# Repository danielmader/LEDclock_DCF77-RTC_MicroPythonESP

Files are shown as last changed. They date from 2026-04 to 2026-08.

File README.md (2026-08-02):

# LEDclock_DCF77-RTC_MicroPythonESP

MicroPython-LED-Uhr auf MAX7219-Punktmatrix-Modulen mit DCF77-Zeitzeichenempfänger,
batteriegepufferter externer RTC (RV-8263), Temperatur-/Luftfeuchtesensor (SHT31)
und Helligkeitssensor (TEMT6000) zur automatischen Display-Dimmung.

Es gibt zwei Hardware-Varianten mit identischer Software:

* **Board 1: ESP-WROOM-32** (NodeMCU)
* **Board 2: ESP32-S3-WROOM-1** (N16R8)

Boardvarianten & Pinbelegung
----------------------------

Die Pinbelegung liegt nicht mehr im Code, sondern in JSON-Dateien in `src/`:

* `board_esp-wroom-32.json` — Board 1
* `board_esp32-s3-wroom-1.json` — Board 2

Das Modul `src/boardconfig.py` erkennt das Board zur Laufzeit automatisch
(über `os.uname().machine`) und lädt die passende Datei. Es genügt also, beide
JSON-Dateien mit auf das Gerät zu kopieren. Für Sonderaufbauten kann eine Datei
`board.json` auf dem Gerät abgelegt werden, die dann Vorrang hat.

| Funktion / Peripherie | Signal | ESP-WROOM-32 | ESP32-S3-WROOM-1 | Anmerkung |
| :--- | :--- | :--- | :--- | :--- |
| I2C (RV-8263, SHT31)  | SDA | GPIO23 | GPIO8 | 50 kHz, interne Pull-ups |
| | SCL | GPIO22 | GPIO9 | |
| TEMT6000 | ADC | GPIO36 (ADC1_CH0) | GPIO4 (ADC1_CH3) | zwingend ADC1 (ADC2 kollidiert mit Wi-Fi) |
| DCF77 | DATA | GPIO13 | GPIO14 | Eingang mit Pull-up |
| MAX7219 | DIN (MOSI)  | GPIO19 | GPIO42 | S3: GPIO19/20 sind USB! |
| | SCLK | GPIO5 | GPIO1 | |
| | CS | GPIO18 | GPIO2 | |
| MAX7219 Power ON/OFF  | GPIO out | – | GPIO21 | optional (`null` in JSON = nicht beschaltet) |
| Status-LED | GPIO out | GPIO2 | – | S3-DevKit hat nur RGB-LED (GPIO48) |

Wichtige Hinweise zum ESP32-S3 (Details in `hardware/Pinout Proposal.md`):

* **GPIO19/20** sind das native USB-Interface — nicht extern beschalten.
* **GPIO0** ist Strapping-Pin (Bootloader) — nicht als Power-Control verwenden.
* **N16R8 (8 MB Octal-PSRAM):** GPIO33–37 sind intern belegt; die herausgeführten
  GPIO35–37 dürfen **nicht** beschaltet werden.

Batterie-Backup für RV-8263 RTC
-------------------------------

Anschlüsse am Beispiel ESP-WROOM-32 (beim ESP32-S3: SDA = GPIO8, SCL = GPIO9):

    ESP-WROOM-32 NodeMCU

    VCC (3.3V ESP) -----------------+-------+-------+
                                    |       |       |
                                    [R1]    [R2]    [D1] (Schottky)
                                    10k     10k     |
                                    |       |       |
    SDA (GPIO 23) ------------------+----------------------- SDA (RV-8263)
                                            |       |
    SCL (GPIO 22) --------------------------+--------------- SCL (RV-8263)
                                                    |
                                                    +------- VCC (RV-8263)
                                                    |
    Batterie (+) ----------[D2] (Schottky) ---------+
    (Knopfzelle)

    GND (ESP) --------------------------------------+------- VSS (RV-8263)
                                                    |
    Batterie (-) -----------------------------------+

* R1 = R2: 10 kOhm
* D1 = D2: Schottky-Diode BAT 42/43 oder BAT 86

Schaltbild Peripherie (ohne Backup-Batterie)
--------------------------------------------

Verdrahtungspläne für beide Boards liegen in `hardware/`:

* [Wiring Diagram ESP-WROOM-32](./hardware/Wiring%20Diagram_ESP-WROOM-32.png) ([PDF](./hardware/Wiring%20Diagram_ESP-WROOM-32.pdf))
* [Wiring Diagram ESP32-S3-WROOM-1](./hardware/Wiring%20Diagram_ESP32-S3-WROOM-1.png) ([PDF](./hardware/Wiring%20Diagram_ESP32-S3-WROOM-1.pdf))

ASCII-Übersicht am Beispiel ESP-WROOM-32:

    ESP-WROOM-32 NodeMCU

    3V3  -----------------------------------+------------------+------------------+
                                            |                  |                  |
                                            |                  |                  +---- VCC (MAX7219)
                                            |                  +----------------------- VCC (TEMT6000)
                                            +------------------------------------------ VCC (I2C: RV-8263, SHT31)

    5V (VIN) --------------------------------------------------- VCC (DCF77)

    GND  -----------------------------------+------------------+------------------+------------------+
                                            |                  |                  |                  |
                                            |                  |                  |                  +---- GND (MAX7219)
                                            |                  |                  +---- GND (DCF77)
                                            |                  +----------------------- GND (TEMT6000)
                                            +------------------------------------------ VSS (I2C: RV-8263, SHT31)

    GPIO23 (SDA) ---------------------------+------------------ SDA (RV-8263)
                                            |
                                            +------------------ SDA (SHT31)

    GPIO22 (SCL) ---------------------------+------------------ SCL (RV-8263)
                                            |
                                            +------------------ SCL (SHT31)

    GPIO36 (ADC) ------------------------------------------------ AO/OUT (TEMT6000)

    GPIO13 -------------------------------------------------------- DATA/OUT (DCF77)

    GPIO19 (SPI MOSI) ------------------------------------------------ DIN (MAX7219)

    GPIO18 (SPI CS) -------------------------------------------------- CS (MAX7219)

    GPIO5  (SPI SCLK) ------------------------------------------------ SCLK (MAX7219)

Hinweis DCF77 Versorgung
------------------------

- Der DCF77-Empfänger kann mit 5V versorgt werden; das ist für die Signalqualität
  oft etwas robuster.
- Wichtig: Das DCF77-Datensignal muss dann auf 3.3V-Pegel zum ESP32 angepasst
  werden (Spannungsteiler, Pegelwandler oder Open-Collector mit 3.3V Pull-up).
- Läuft das Modul sauber mit 3.3V, ist das meist die einfachste und sicherste
  Lösung, weil kein Pegelwandler nötig ist.
- DCF77-Empfänger reagieren empfindlich auf Wi-Fi-Störungen und sollten räumlich
  getrennt vom ESP32 platziert werden.

Software
--------

Die Skripte liegen in `src/`:

* `main.py` — Hauptprogramm (asyncio-Tasks: DCF77-Empfang, Zeit-Sync, Sensorik, Anzeige)
* `boardconfig.py` — lädt die Pinbelegung aus `board_*.json` (Auto-Erkennung)
* `dcf77.py` — DCF77-Dekoder
* `rv8263.py` — Treiber externe RTC RV-8263
* `sht31.py` — Treiber Temperatur-/Feuchtesensor SHT31
* `temt6000.py` — Treiber Helligkeitssensor TEMT6000
* `max7219wrapper.py`, `characters.py` — Display-Ansteuerung und Fonts
* `lib/max7219.py` — MAX7219-Basistreiber (mcauser), auf dem Gerät nach `/lib`
* `playground/` — Diagnose-Skripte (DCF77-Analyzer, I2C-Diagnose)

Deployment z.B. mit `mpremote`: alle `.py` aus `src/` sowie **beide**
`board_*.json` ins Wurzelverzeichnis des Geräts kopieren, `src/lib/max7219.py`
nach `/lib/max7219.py`.

Entwicklung: Linting & Typechecking
-----------------------------------

### Einrichtung der venv

Die Konfigurationen (`pyrightconfig.json`, `scripts/update-typeshed.sh`) erwarten
die venv unter `.venv` mit **Python 3.11**. Einrichtung wahlweise mit pip oder uv:

    ## Variante A: pip/venv
    python3.11 -m venv .venv
    .venv/bin/pip install -r requirements.txt

    ## Variante B: uv
    uv venv --python 3.11 .venv
    uv pip install -r requirements.txt

    ## Danach in beiden Fällen: kombiniertes Typeshed für ty erzeugen
    ./scripts/update-typeshed.sh

`requirements.txt` enthält alles Nötige:

* `micropython-esp32-stubs` — Typ-Stubs für `machine`, `network`, `time.ticks_ms()`
  usw. (zieht `micropython-stdlib-stubs` automatisch mit)
* `basedpyright` — Typechecker, gleiche Engine wie Pylance
* `ty` — Typechecker von Astral (Hersteller von ruff/uv)
* `ruff` — Linter (Import-Sortierung, Code-Stil, Komplexität)

*(Hinweis: Das npm-Paket `pyright` selbst braucht eine Node-Runtime mit
`libatomic.so.1` — `basedpyright` bringt dagegen alles als Python-Wheel mit
und liest dieselbe `pyrightconfig.json`.)*

### Checker ausführen

    .venv/bin/basedpyright src    ## Konfiguration: pyrightconfig.json
    .venv/bin/ty check            ## Konfiguration: pyproject.toml [tool.ty]
    .venv/bin/ruff check src      ## Linter, Konfiguration: pyproject.toml [tool.ruff]

Alle drei müssen fehlerfrei durchlaufen (Stand der letzten Bereinigung:
0 Fehler / "All checks passed").

### Wie die Stub-Auflösung funktioniert (wichtig bei Problemen)

Die MicroPython-Stubs liegen nach der Installation **flach** in den
site-packages (`time.pyi`, `machine.pyi`, ...), zusätzlich liefert
`micropython-stdlib-stubs` ein partielles `stdlib/`-Verzeichnis (u.a. `asyncio`
mit `sleep_ms`). Die beiden Checker finden sie unterschiedlich:

* **basedpyright/Pylance:** über `stubPath` **und** `typeshedPath` in
  `pyrightconfig.json` — beide zeigen auf
  `.venv/lib/python3.11/site-packages`. Bei einem Wechsel der Python-Version
  müssen diese Pfade angepasst werden!
* **ty:** kennt keinen `stubPath`, sondern nur ein komplettes Ersatz-Typeshed
  (`[tool.ty.environment].typeshed = ".typeshed"` in `pyproject.toml`).
  `scripts/update-typeshed.sh` baut dieses Verzeichnis aus den installierten
  Stubs zusammen (stdlib-Stubs + das dort fehlende `time.pyi`).
  **Nach jedem Update der Stubs erneut ausführen:**

      .venv/bin/pip install -U micropython-esp32-stubs   ## bzw. uv pip install -U ...
      ./scripts/update-typeshed.sh

### Bekannte Stolperfallen (ty 0.0.65)

* Das generierte Typeshed darf **nicht** `typings/` heißen (implizites
  Stub-Verzeichnis von ty → Absturz "dependency graph cycle"). Deshalb `.typeshed/`.
* `src` nicht zusätzlich in `[tool.ty.environment].extra-paths` eintragen —
  es ist bereits First-Party-Root, die Doppelung führt ebenfalls zum Absturz.
* ty versteht mypy-Fehlercodes nicht: `# type: ignore[operator]` unterdrückt
  nur Pylance/basedpyright. Für ty muss zusätzlich `# ty: ignore[<regel>]` an
  die Zeile (Beispiele in `main.py` bei der Driftkompensation).
* Ticks sind in den Stubs bewusst opak typisiert (`_TicksMs`): direkte
  Arithmetik wie `ticks_ms() % 1000` wird angemeckert — gewollt ist
  `time.ticks_diff()` / `time.ticks_add()`.

### VSCode

Empfohlene Extensions: **Pylance** (oder basedpyright) und **ty**. Damit die
Extensions die Checker aus der venv verwenden, stehen in der Workspace-Datei
(`*.code-workspace` ist gitignored, ggf. neu anlegen):

    "settings": {
        "python.defaultInterpreterPath": "${workspaceFolder}/.venv/bin/python",
        "ty.importStrategy": "fromEnvironment",
        "basedpyright.importStrategy": "fromEnvironment"
    }

ASCII-Boardplan DIN-Lochraster 32x54 (einseitig, ESP-WROOM-32)
--------------------------------------------------------------

Schienen horizontal, Signale vertikal mit Drahtbruecken.

        +----------------------------------------------------+
    01  |5V==================================================|
        |....................................................|
        |3V3=================================================|
        |....................................................|
    05  |GND=================================================|
        |....................................................|
        |SDA=================================================|
        |SCL=================================================|
        |....................................................|
    10  |...................ESP32 NodeMCU....................|
        |   L01 3V3    o......................o GND    R01   |
        |   L02 RESET  o......................o GPIO23 R02   |
        |   L03 GPIO36 o......................o GPIO22 R03   |
        |   L04 GPIO39 o......................o INT    R04   |
    15  |   L05 GPIO34 o......................o INT    R05   |
        |   L06 GPIO35 o......................o GPIO21 R06   |
        |   L07 GPIO32 o......................o GND    R07   |
        |   L08 GPIO33 o......................o GPIO19 R08   |
        |   L09 GPIO25 o......................o GPIO18 R09   |
    20  |   L10 GPIO26 o......................o GPIO5  R10   |
        |   L11 GPIO27 o......................o GPIO17 R11   |
        |   L12 GPIO14 o......................o GPIO16 R12   |
        |   L13 GPIO12 o......................o GPIO4  R13   |
        |   L14 GND    o......................o GPIO0  R14   |
    25  |   L15 GPIO13 o......................o GPIO2  R15   |
        |   L16 INT    o......................o GPIO15 R16   |
        |   L17 INT    o......................o INT    R17   |
        |   L18 INT    o......................o INT    R18   |
        |   L19 5V     o......................o INT    R19   |
    30  |....................................................|
        |....................................................|
        |....................................................|
        +----------------------------------------------------+

Pinouts
-------

### RV-8263
* NC
* Vss
* NC (CLKOE)
* NC (INT)
* VDD
* NC (CLKOUT)
* SCL
* SDA

### SHT31
* VING
* GND
* SCL
* SDA

### TEMT6000
* OUT
* GND
* VCC

### DCF77
* VIN
* SIG
* GND

### MAX7219
* VCC
* GND
* DIN
* CS
* CLK

Lochrasterplatinenlayout
------------------------

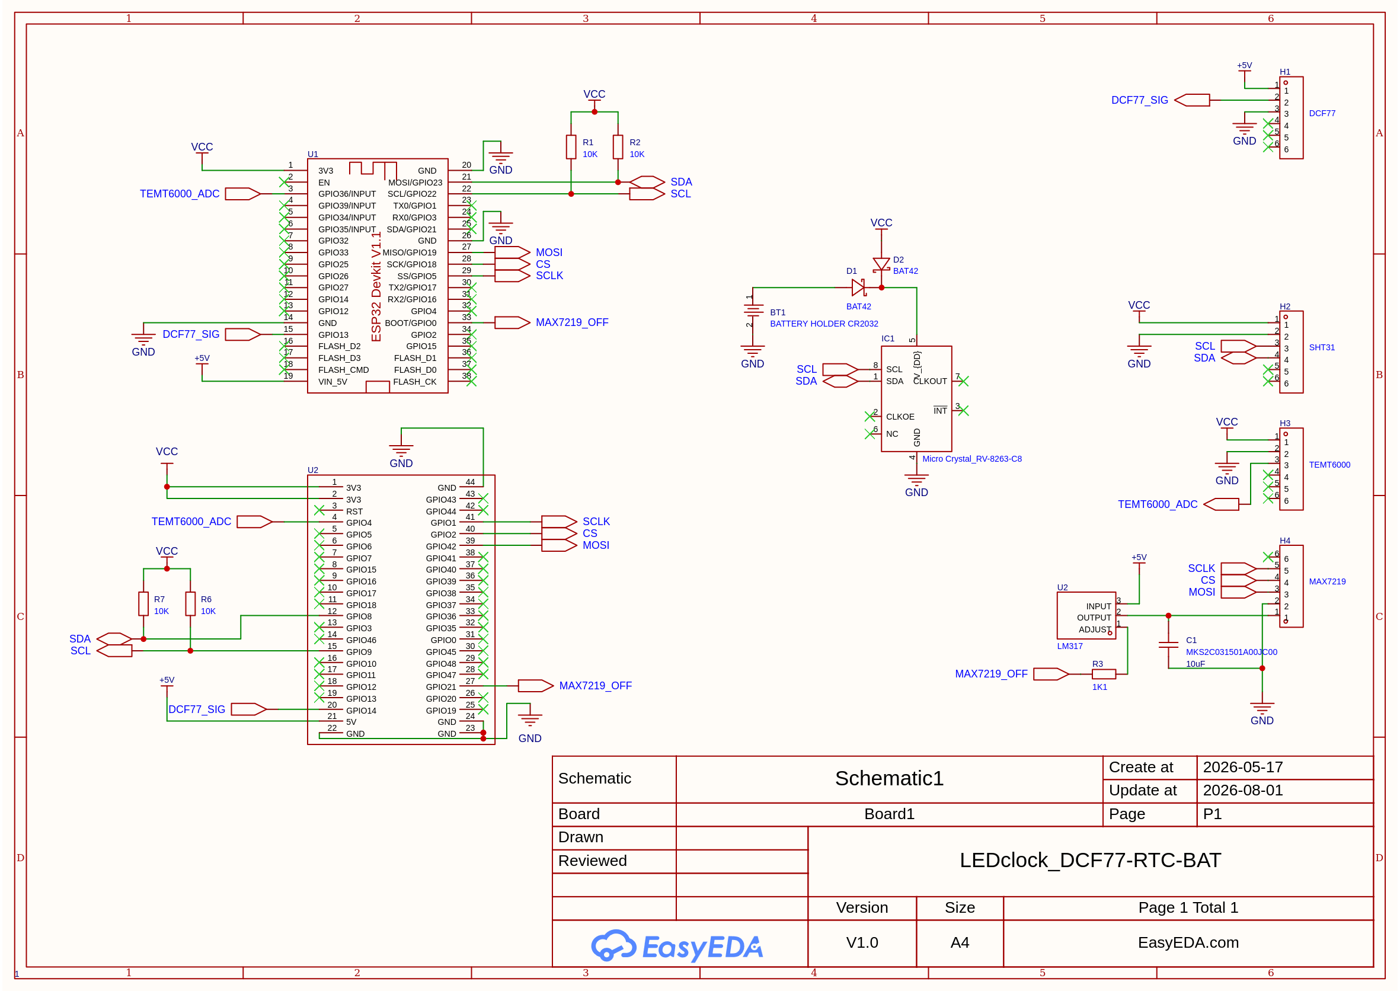
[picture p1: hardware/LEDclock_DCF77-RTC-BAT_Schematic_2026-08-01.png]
Schaltplan


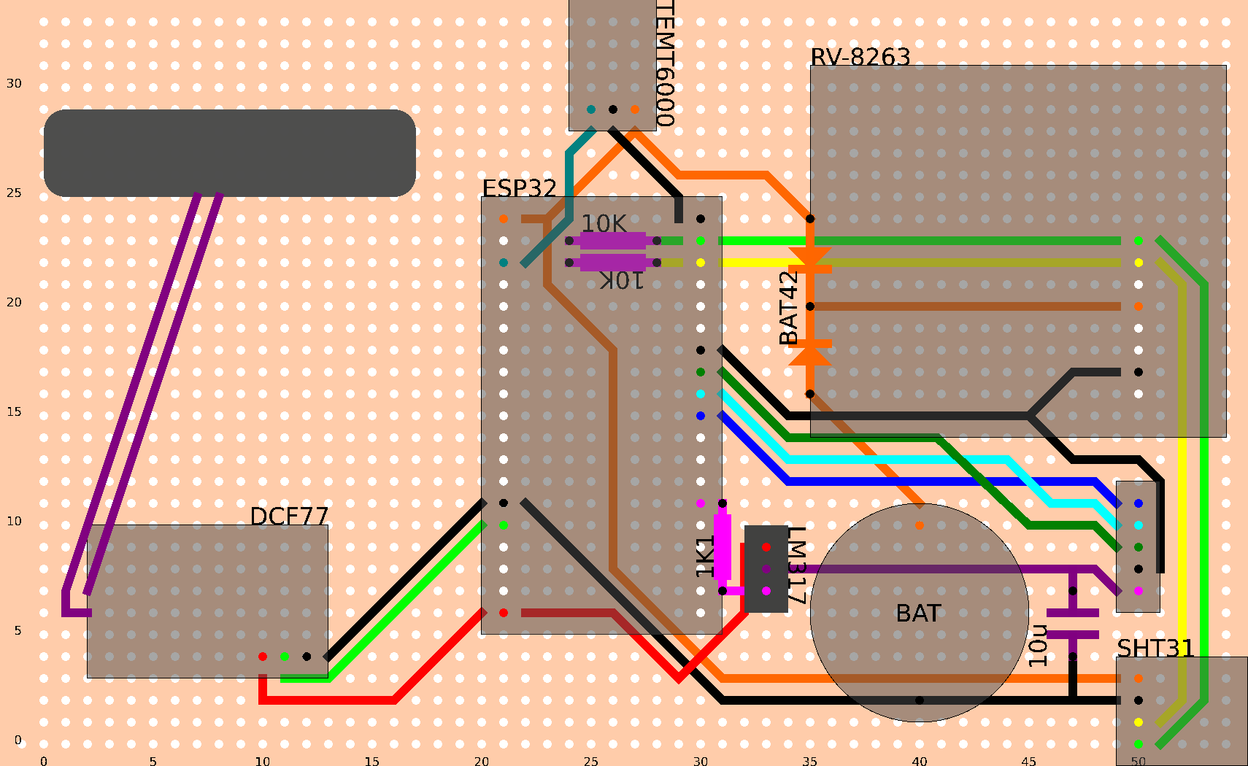
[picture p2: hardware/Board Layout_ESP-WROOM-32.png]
Board Layout ESP-WROOM-32


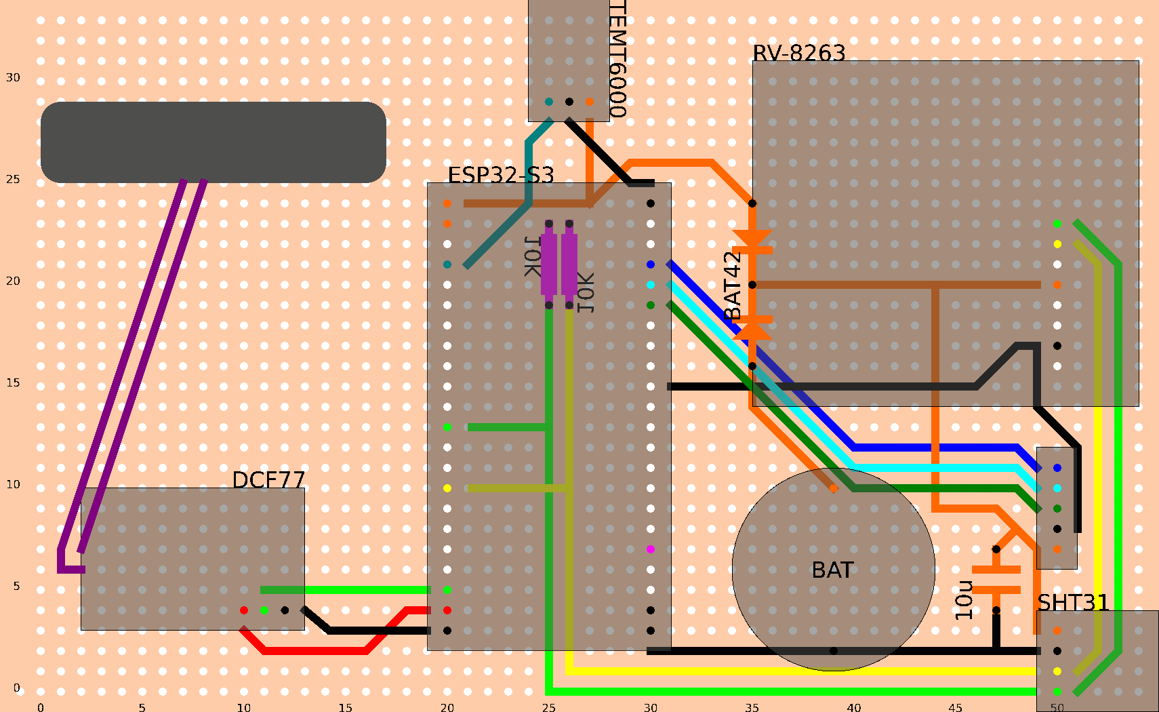
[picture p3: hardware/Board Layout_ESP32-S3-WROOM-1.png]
Board Layout ESP32-S3-WROOM-1


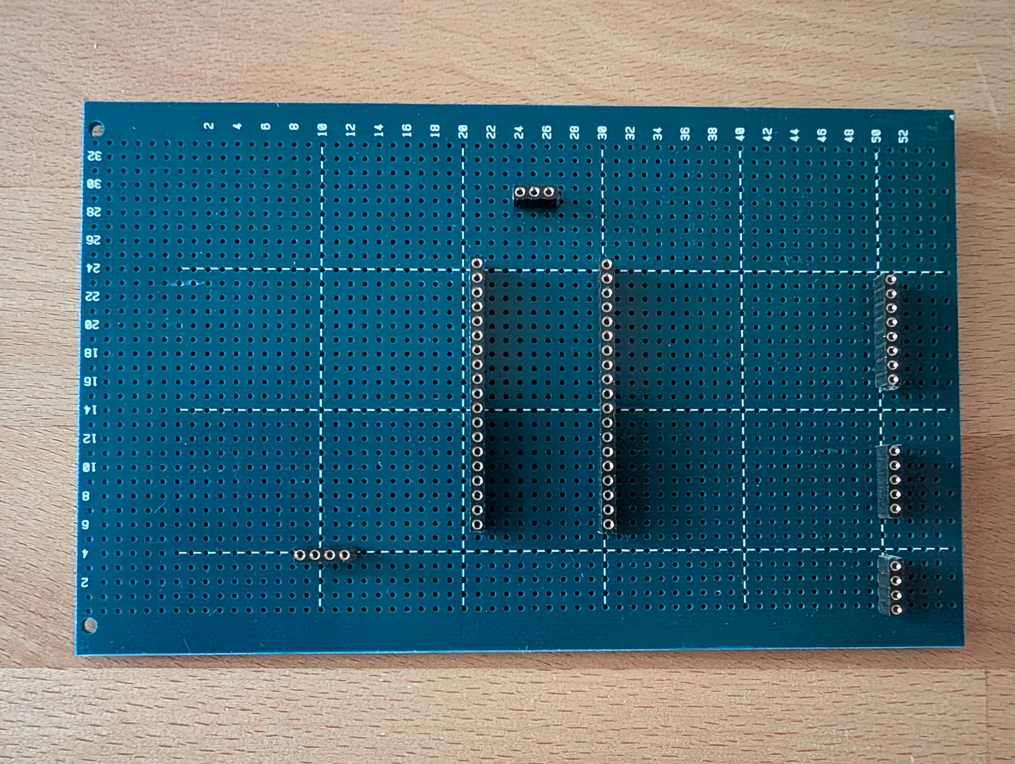
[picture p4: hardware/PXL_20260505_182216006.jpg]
Grundriss


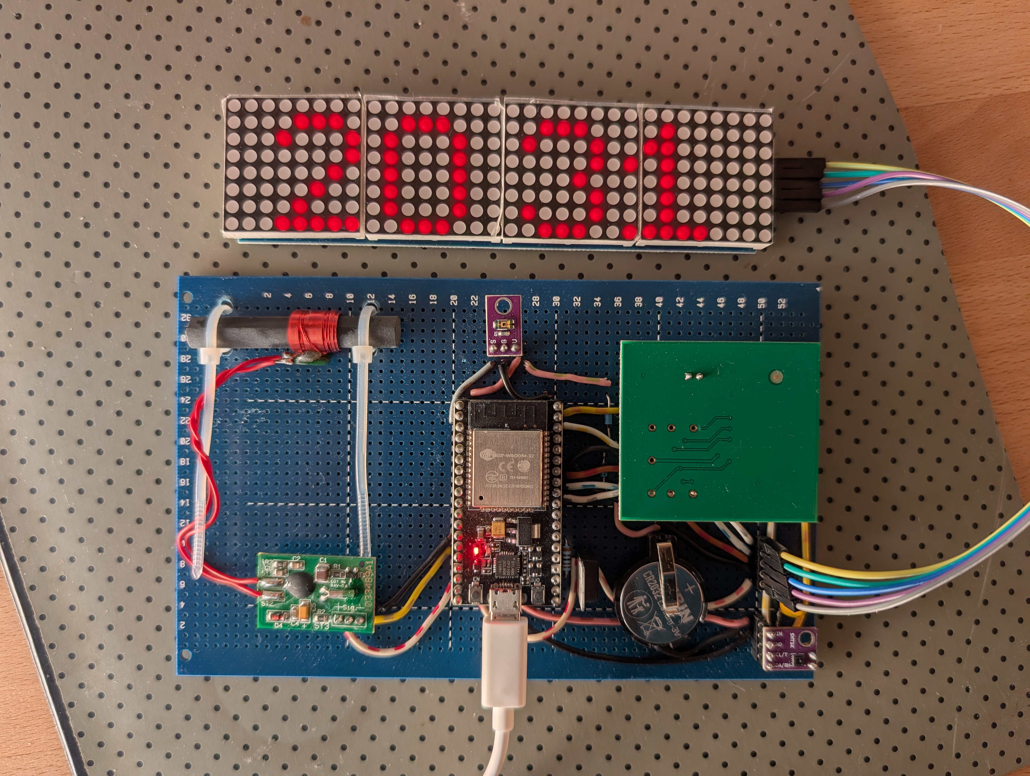
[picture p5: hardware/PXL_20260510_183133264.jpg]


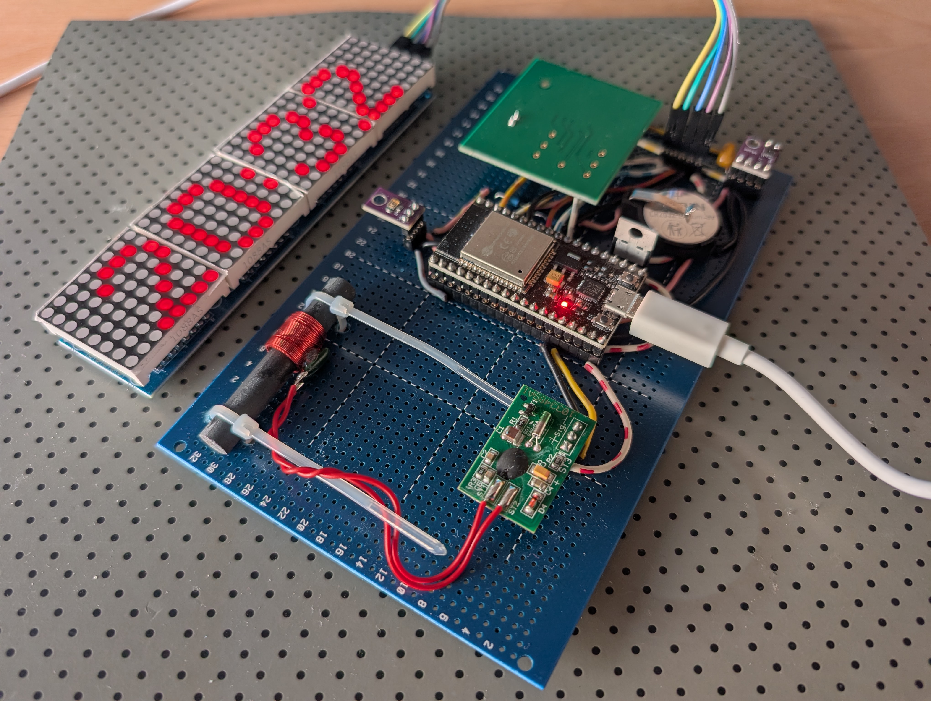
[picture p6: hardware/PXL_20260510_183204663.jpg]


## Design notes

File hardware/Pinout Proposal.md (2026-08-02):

# Pinbelegungs-Dokumentation: ESP-WROOM-32 vs. ESP32-S3-WROOM-1

Beim Upgrade vom klassischen **ESP-WROOM-32** auf den neueren **ESP32-S3-WROOM-1** ändern sich einige Hardware-Peripherien und Standard-Pinbelegungen. Dank der flexiblen **GPIO-Matrix** (GPIO Mux) des ESP32 lassen sich viele Signale im Code frei auf andere Pins umleiten. Dennoch müssen spezifische Board-Eigenschaften (Strapping-Pins, USB-Interfaces, Octal-PSRAM) beachtet werden.

---

## 1. I2C-Bus (Temperatur-Sensor SHT31 & RTC RV-8263)

Beide I2C-Sensoren liegen parallel als Bus-Teilnehmer an denselben zwei Leitungen (`SDA` und `SCL`).

* **ESP-WROOM-32 (Standard):** `GPIO 23` (SDA) und `GPIO 22` (SCL).
* **ESP32-S3 (Standard):** `GPIO 8` (SDA) und `GPIO 9` (SCL).
* **Begründung & Wahl:**
  Beim Wechsel auf den ESP32-S3 wurden die neuen Hardware-Defaults **GPIO 8 (SDA)** und **GPIO 9 (SCL)** übernommen. Diese Pins sind frei von Strapping-Funktionen und ideal für I2C geeignet.

---

## 2. ADC / Analog-Eingang (TEMT6000 Helligkeitssensor)

Der analoge Lichtsensor benötigt einen ADC-Pin.

* **ESP-WROOM-32:** `GPIO 36` (VP / ADC1_CH0).
* **ESP32-S3:** `GPIO 4` (ADC1_CH3).
* **Begründung & Wahl:**
  Auf beiden Boards muss zwingend ein Kanal des **ADC1** gewählt werden, da ADC2 deaktiviert wird, sobald Wi-Fi aktiv genutzt wird. Beim ESP32-S3 fällt die Wahl auf **GPIO 4**, was ein unproblematischer ADC1-Eingang ist.
  *(Hinweis: Pins wie GPIO 35–37 dürfen beim S3-Board keinesfalls genutzt werden – siehe Abschnitt 6).*

---

## 3. GPIO Input (DCF77-Zeitsignal)

Das DCF77-Signal ist sehr langsam und benötigt keinen speziellen Hardware-Schnittstellen-Pin.

* **ESP-WROOM-32:** `GPIO 13`.
* **ESP32-S3:** `GPIO 14`.
* **Begründung & Wahl:**
  Auf beiden Boards wird ein Standard-GPIO genutzt. Auf dem S3-Board fällt die Wahl auf **GPIO 14**.
  *_Tipp: DCF77-Empfänger reagieren empfindlich auf Wi-Fi-Störungen und sollten räumlich getrennt vom ESP32 platziert werden._*

---

## 4. SPI-Bus (MAX7219 LED-Matrix)

Für die Übertragung an die LED-Matrix werden MOSI (Data), SCLK (Clock) und CS (Chip Select) benötigt.

* **ESP-WROOM-32 (Bisher):** `GPIO 19` (MOSI), `GPIO 5` (SCLK), `GPIO 18` (CS).
* **ESP32-S3 (Standard vs. Gewählt):**
  * *S3-Defaults:* `GPIO 11` (MOSI), `GPIO 12` (SCLK), `GPIO 10` (CS).
  * *Gewählte Ausweich-Pins:* **`GPIO 42` (MOSI)**, **`GPIO 1` (SCLK)**, **`GPIO 2` (CS)**.
* **Begründung der Abweichung:**
  * **Warum nicht GPIO 19, 20, 21 vom alten Board?** Beim ESP32-S3 sind GPIO 19 (`USB_D-`) und GPIO 20 (`USB_D+`) für das native USB-Interface reserviert. Eine Belegung führt zu Konflikten beim Flashen und Debuggen.
  * **Warum GPIO 1, 2, 42?** Diese Pins liegen auf der rechten Board-Seite direkt nebeneinander und bieten eine hervorragende Platine-Leitungsführung. Es handelt sich um vollwertige Digital-IOs ohne störende Strapping- oder System-Konflikte.

---

## 5. Display-Schalter (MAX7219 Power Cutoff / OFF)

Pin zur Ansteuerung des Versorgungsspannungsschalters für die Matrix.

* **ESP-WROOM-32 (Bisher angedacht):** `GPIO 0`.
* **ESP32-S3 (Gewählt):** `GPIO 21`.
* **Begründung & Korrektur:**
  * **Korrektur zu GPIO 0:** `GPIO 0` ist auf beiden Chips ein kritischer **Strapping-Pin** (Bootloader-Auswahl). Wird er beim Starten extern auf GND gezogen, schaltet der ESP in den Boot-Modus und startet den Code nicht.
  * **Wahl von GPIO 21:** Auf dem ESP32-S3 ist **GPIO 21** ein vollkommen freier Digital-Pin (RTC-fähig, aber ohne Boot-Einfluss). Er eignet sich ideal, um das Display sicher ein- und auszuschalten.

---

## 6. Wichtiger Sonderhinweis: Octal-PSRAM (N16R8)

Auf dem vorliegenden ESP32-S3-Modul ist die Variante **ESP32-S3-WROOM-1 N16R8** verbaut.

* **8 MB PSRAM = Octal SPI (OPI):** Bei allen ESP32-S3 mit 8 MB PSRAM belegt der RAM-Speicher intern fest die Pins **GPIO 33 bis GPIO 37**.
* **Auswirkung:** Die Pins GPIO 35, 36 und 37, die auf dem Pinout rausgeführt sind, dürfen **nicht extern beschaltet werden**! Eine Nutzung führt zum Absturz des Systems.

---

## 7. Zusammenfassende Pinbelegungs-Tabellen

### Board 1: ESP-WROOM-32 (Alt)

| Funktion / Peripherie | Signal / Rolle | Standard-Pin | Gewählter Pin | Anmerkung |
| :--- | :--- | :--- | :--- | :--- |
| **I2C-Bus** | SDA | GPIO 23 | **GPIO 23** | Standard I2C |
| | SCL | GPIO 22 | **GPIO 22** | Standard I2C |
| **ADC** | TEMT6000 | GPIO 36 | **GPIO 36** | ADC1_CH0 |
| **GPIO In** | DCF77 Signal | - | **GPIO 13** | Standard GPIO |
| **SPI-Bus** | MOSI (DIN) | GPIO 23 | **GPIO 19** | Per Hardware-Matrix umgeleitet |
| | SCLK | GPIO 18 | **GPIO 5** | Per Hardware-Matrix umgeleitet |
| | CS | GPIO 5 | **GPIO 18** | Per Hardware-Matrix umgeleitet |
| **Power-Control** | MAX7219 OFF | - | **GPIO 0** | *Kritisch:* Strapping-Pin! |

---

### Board 2: ESP32-S3-WROOM-1 (Neu, N16R8)

| Funktion / Peripherie | Signal / Rolle | Standard-Pin (FSPI/I2C) | Gewählter Pin | Anmerkung & Grund für Wahl |
| :--- | :--- | :--- | :--- | :--- |
| **I2C-Bus** | SDA | GPIO 8 | **GPIO 8** | S3-I2C Standard |
| | SCL | GPIO 9 | **GPIO 9** | S3-I2C Standard |
| **ADC** | TEMT6000 | GPIO 4 | **GPIO 4** | ADC1_CH3 (Sicher vor Wi-Fi-Konflikten) |
| **GPIO In** | DCF77 Signal | - | **GPIO 14** | Standard-GPIO |
| **SPI-Bus** | MOSI (DIN) | GPIO 11 | **GPIO 42** | Meidet GPIO 19/20 (USB) |
| | SCLK | GPIO 12 | **GPIO 1** | Meidet GPIO 19/20 (USB) |
| | CS | GPIO 10 | **GPIO 2** | Meidet GPIO 19/20 (USB) |
| **Power-Control** | MAX7219 OFF | - | **GPIO 21** | Sicherer Ersatz für GPIO 0 (Kein Boot-Pin) |

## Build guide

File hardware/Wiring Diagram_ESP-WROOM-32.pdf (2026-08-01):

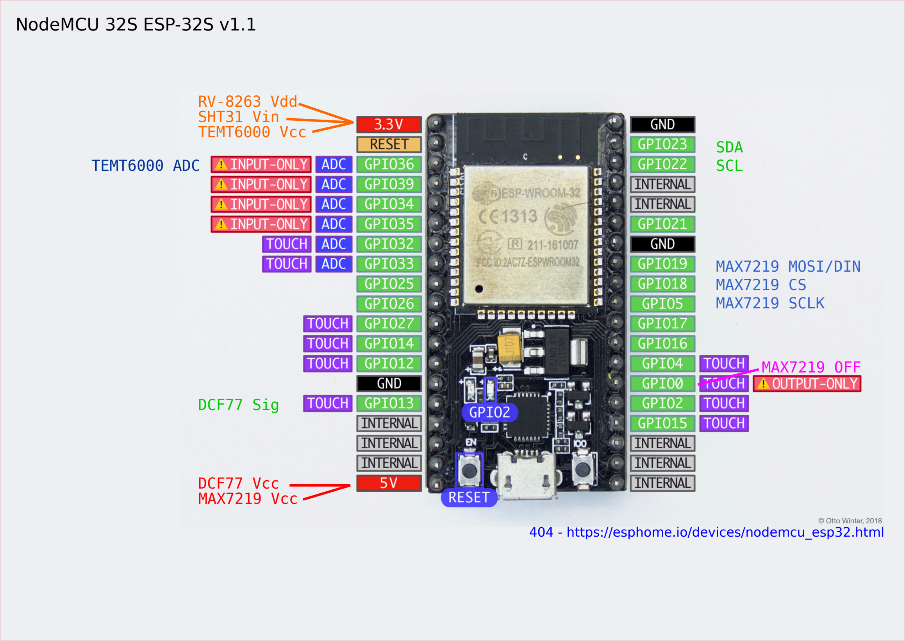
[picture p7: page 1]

404 - https://esphome.io/devices/nodemcu_esp32.html

DCF77 Vcc

SDA
SCL

DCF77 Sig

RV-8263 Vdd

MAX7219 Vcc

TEMT6000 Vcc

TEMT6000 ADC

MAX7219 SCLK

MAX7219 MOSI/DIN
MAX7219 CS

MAX7219 OFF

SHT31 Vin

NodeMCU 32S ESP-32S v1.1

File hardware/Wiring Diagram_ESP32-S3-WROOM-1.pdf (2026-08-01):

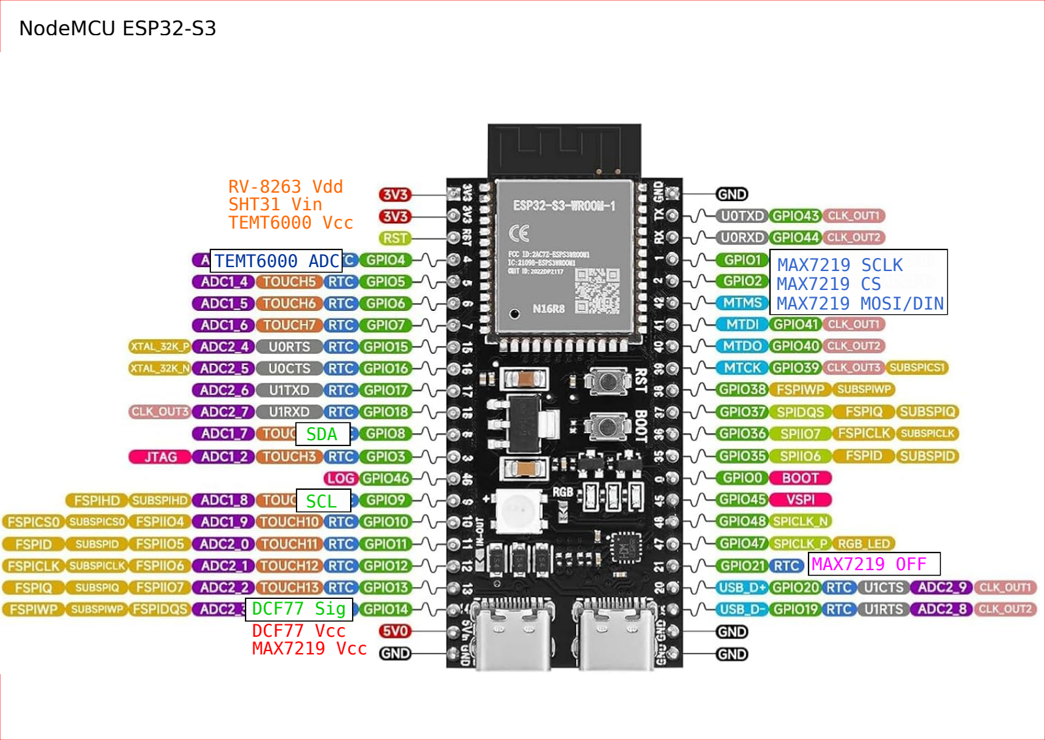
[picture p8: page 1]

SDA

SCL

MAX7219 Vcc

MAX7219 OFF

DCF77 Vcc

DCF77 Sig

RV-8263 Vdd

TEMT6000 Vcc

TEMT6000 ADC

SHT31 Vin

NodeMCU ESP32-S3

MAX7219 MOSI/DIN

MAX7219 CS

MAX7219 SCLK

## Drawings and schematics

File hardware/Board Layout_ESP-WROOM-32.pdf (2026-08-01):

# ESP32

RV-8263

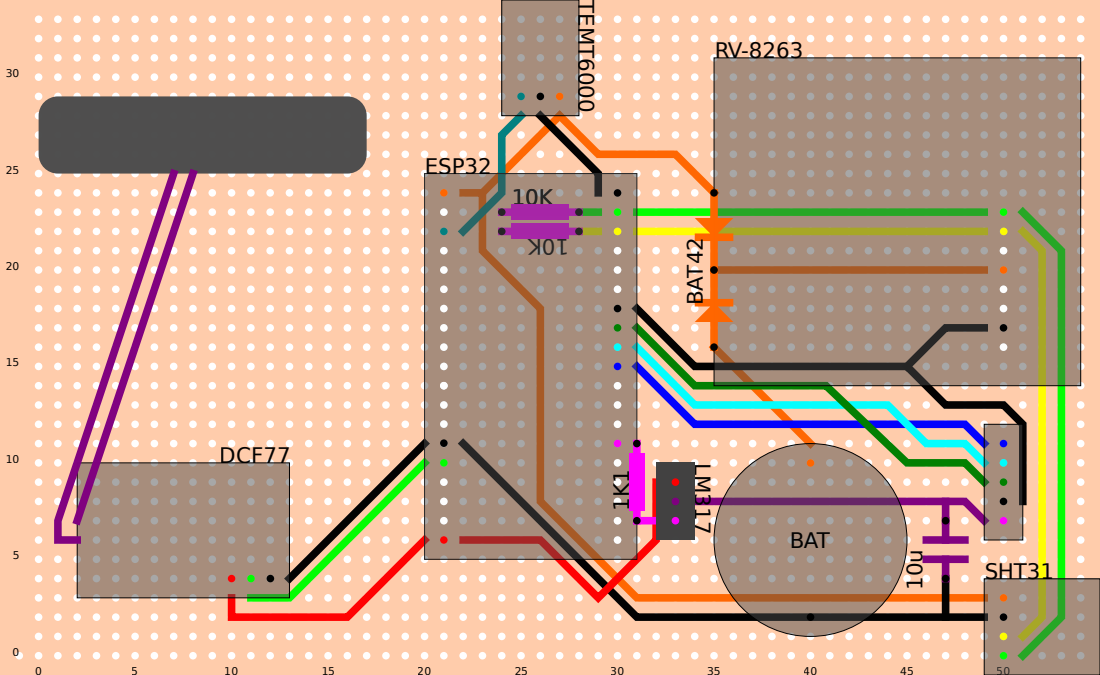
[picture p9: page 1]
DCF77; SHT31; TEMT6000; BAT; BAT42

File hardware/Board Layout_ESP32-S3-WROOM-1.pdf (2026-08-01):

# ESP32-S3

RV-8263

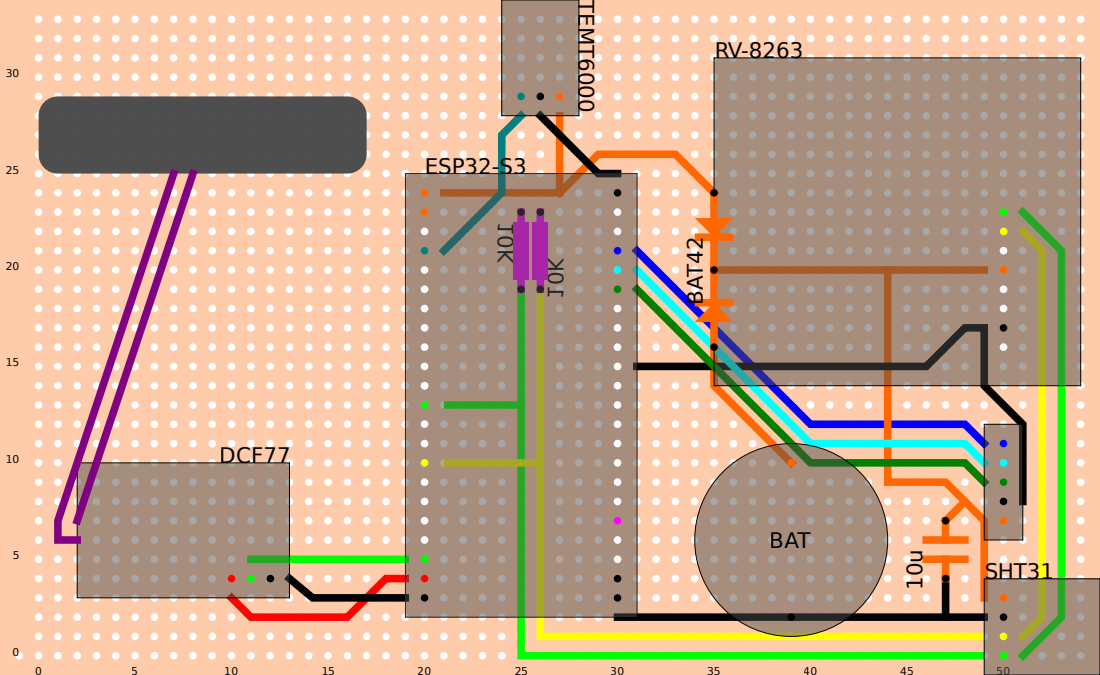
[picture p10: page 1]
DCF77; SHT31; TEMT6000; BAT; BAT42

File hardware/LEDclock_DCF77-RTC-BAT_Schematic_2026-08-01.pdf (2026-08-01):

### SCL

### VCC

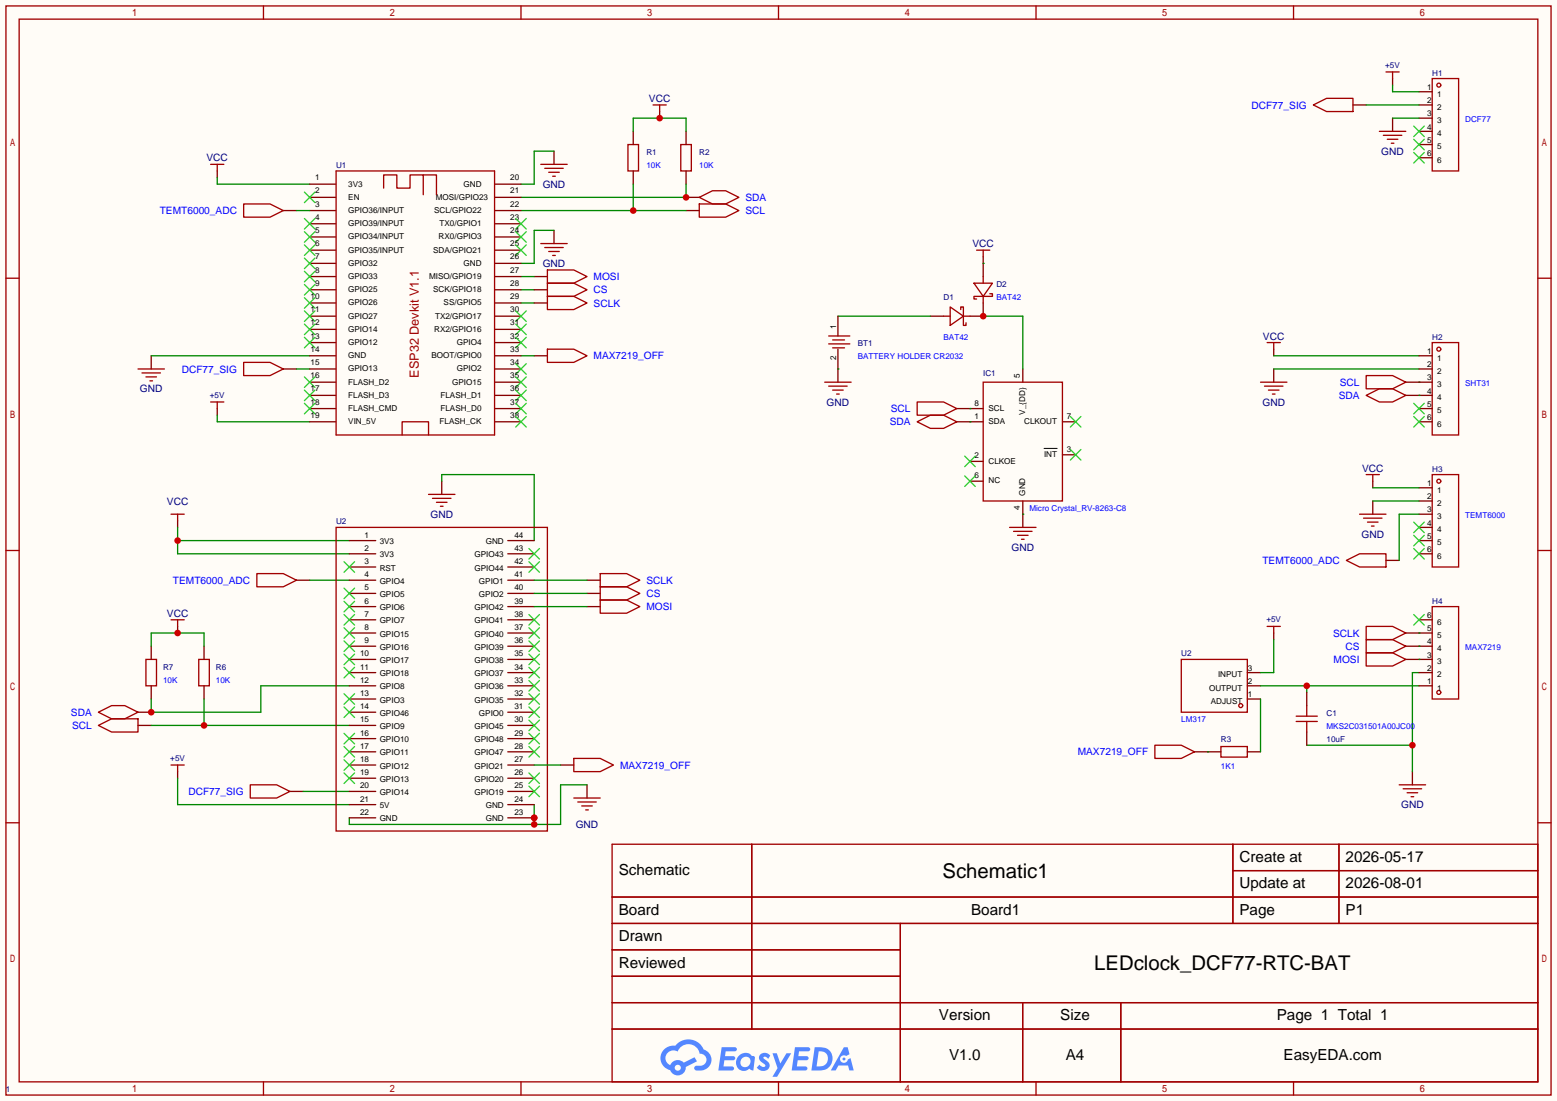
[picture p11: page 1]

Schematic | Schematic1 | Create at | 2026-05-17

Update at | 2026-08-01

Board | Board1 | Page | P1
Drawn | | LEDclock_DCF77-RTC-BAT
Reviewed

Version | Size | Page 1 Total 1

V1.0 | A4 | EasyEDA.com

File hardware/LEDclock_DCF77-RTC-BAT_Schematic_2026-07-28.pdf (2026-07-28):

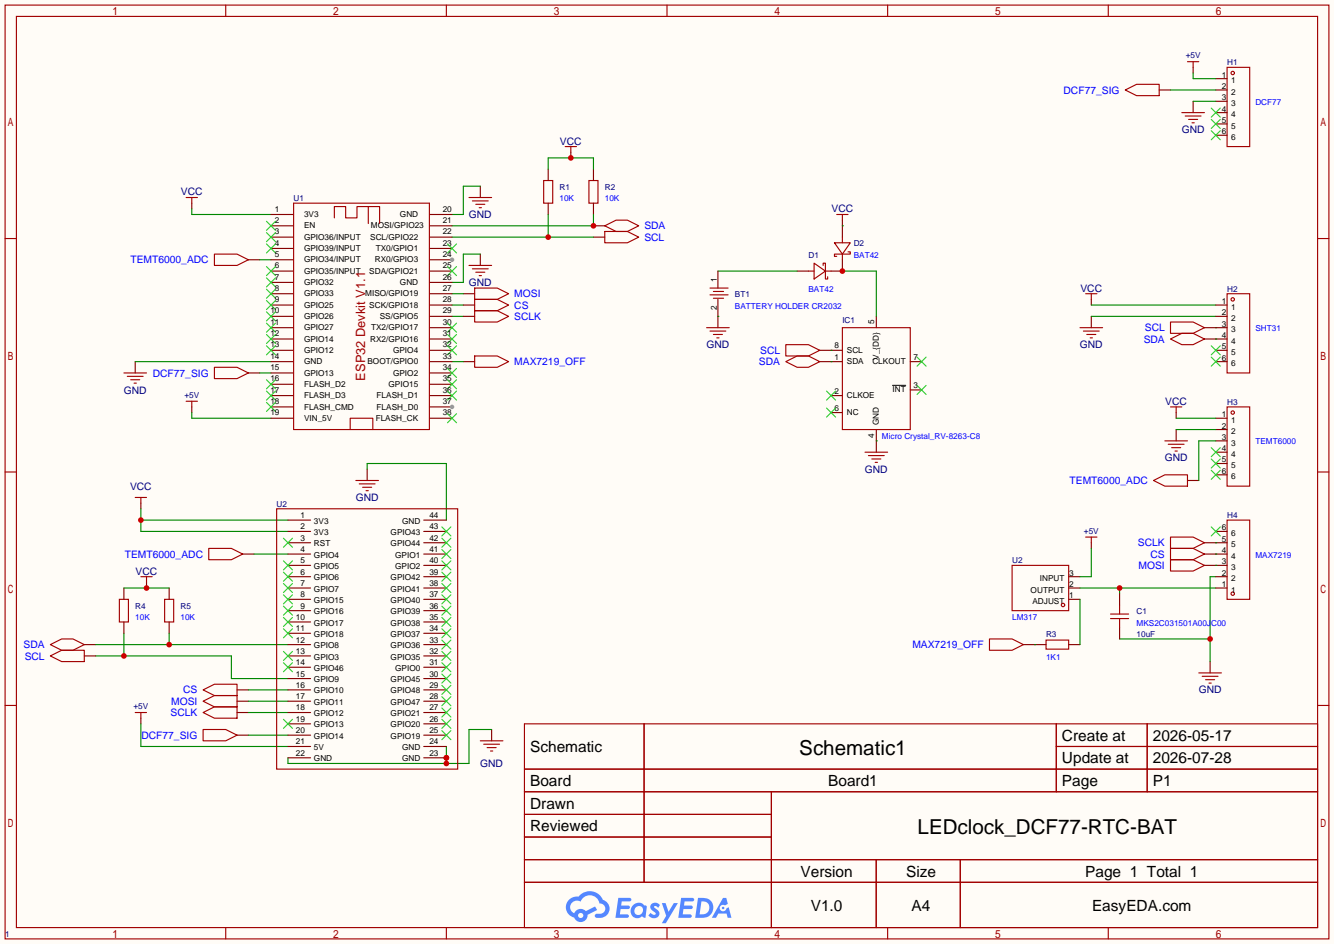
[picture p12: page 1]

Schematic | Schematic1 | Create at | 2026-05-17

Update at | 2026-07-28

Board | Board1 | Page | P1
Drawn | | LEDclock_DCF77-RTC-BAT
Reviewed

Version | Size | Page 1 Total 1
V1.0 | A4 | EasyEDA.com

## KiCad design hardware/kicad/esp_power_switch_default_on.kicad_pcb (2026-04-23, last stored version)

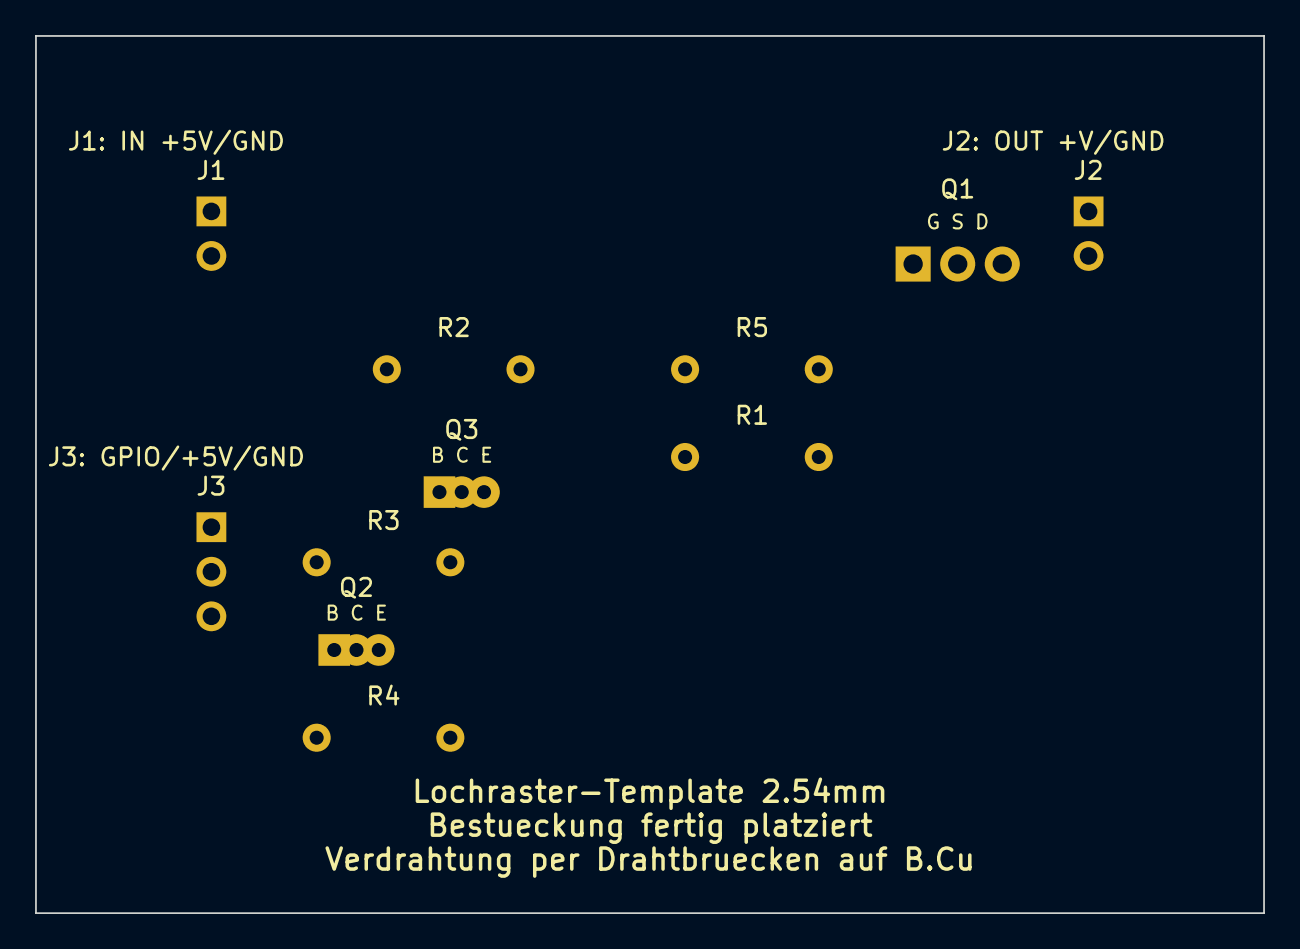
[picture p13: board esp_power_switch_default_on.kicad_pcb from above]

Board: 2 copper layers, 70.0 x 50.0 mm, 11 parts (0 on the bottom side), 8 nets, no tracks yet.

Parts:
J1: IN_5V_GND; PinHeader_1x02_P2.54mm_Vertical
J2: OUT_V_GND; PinHeader_1x02_P2.54mm_Vertical
J3: ESP_GPIO_HDR; PinHeader_1x03_P2.54mm_Vertical
Q1: FQP27P06; TO-220-3_Vertical
Q2: BC337; TO-92_Inline
Q3: BC327; TO-92_Inline
R1, R4: 100k; R_Axial_DIN0207_L6.3mm_D2.5mm_P7.62mm_Horizontal
R2: 47k; R_Axial_DIN0207_L6.3mm_D2.5mm_P7.62mm_Horizontal
R3: 10k; R_Axial_DIN0207_L6.3mm_D2.5mm_P7.62mm_Horizontal
R5: 220; R_Axial_DIN0207_L6.3mm_D2.5mm_P7.62mm_Horizontal

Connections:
+5V: J1.1, J3.2, Q1.2, Q3.3, R2.1
+V_BAUTEIL: J2.1, Q1.3
ESP_GPIO: J3.1, R3.1
GND: J1.2, J2.2, J3.3, Q2.3, R1.2, R4.2
Q1_GATE: Q1.1, R1.1, R5.2
Q2_BASE: Q2.1, R3.2, R4.1
Q2_COL: Q3.2, R5.1
Q3_BASE: Q2.2, Q3.1, R2.2

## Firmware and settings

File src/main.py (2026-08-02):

import asyncio
import time

import machine

import boardconfig
import dcf77
import max7219wrapper
import rv8263
import sht31
import temt6000

## --- Hardware-Setup ----------------------------------------------------------
## Die Pinbelegung liegt in board_*.json und wird von boardconfig automatisch
## anhand des erkannten Boards (ESP-WROOM-32 bzw. ESP32-S3-WROOM-1) geladen.

print("System-Boot: Initialisiere Komponenten...")

## 1) Interne RTC des ESP32
rtc_internal = machine.RTC()

## 2) I2C-Bus-Initialisierung (Pins & Frequenz aus Board-Konfiguration)
i2c = boardconfig.get_i2c()
print("Initialisiere I²C Bus...")
devices = i2c.scan()
print("Gefundene I²C Adressen:", [hex(d) for d in devices])

## 3) I2C-Geräte erkennen und initialisieren
## Externe RTC 'RV-8263'
rtc_external = rv8263.RV8263(i2c)
rtc_external.init_rtc()
## Temperatur- und Luftfeuchtigkeitssensor SHT31
temphum_sensor = sht31.SHT31(i2c)
_latest_temp = None
_latest_hum = None

## 4) Helligkeitssensor TEMT6000
adc_pin = boardconfig.get_adc_pin()
light_sensor = temt6000.TEMT6000(adc_pin)
_latest_lux_perc = None

## 5) DCF77-Sensor
dcf_pin = boardconfig.get_dcf_pin()
dcf = dcf77.DCF77(dcf_pin, led_pin=None)  # Optional: Status-LED zur Visualisierung der Signalverarbeitung (boardconfig.get_status_led_pin())
DCF_MIN_YEAR = 2020
MAX_SYNC_JUMP_SECONDS = 12 * 60 * 60
DCF_PROGRESS_TOLERANCE_SECONDS = 20
_last_dcf_candidate = None
_last_dcf_candidate_ticks = None

## 6) MAX7219-LED-Matrix (2x 4 Module à 8x8 LEDs = 2x 32x8)
## Baudrate (Key 'spi.baudrate' in der JSON-Datei):
## * 500 kHz für maximale Stabilität bei langen Kabeln oder vielen Modulen
## * 1 MHz für flüssigere Darstellung
## * 10 MHz für maximale Performance (nur bei sehr kurzen Kabeln und wenigen Modulen stabil)
spi = boardconfig.get_spi()
cs = boardconfig.get_spi_cs()
power_pin = boardconfig.get_display_power_pin()  # None, wenn kein separater Power-Control-Pin vorhanden ist (null in JSON)
display = max7219wrapper.Max7219Matrix(spi, cs, num_modules=8, power_pin=power_pin, modules_per_row=4)

## --- Hilfsfunktionen ---------------------------------------------------------

def _is_leap_year(year: int) -> bool:
    """Prüft, ob ein Jahr ein Schaltjahr ist.

    Parameter
    ---------
    * year: Kalenderjahr

    Returns
    -------
    * bool: True bei Schaltjahr
    """
    return (year % 4 == 0 and year % 100 != 0) or (year % 400 == 0)


def _days_in_month(year: int, month: int) -> int:
    """Gibt die Anzahl Tage eines Monats zurück.

    Parameter
    ---------
    * year: Kalenderjahr
    * month: Monat 1..12

    Returns
    -------
    * int: Anzahl Tage im Monat
    """
    if month == 2:
        return 29 if _is_leap_year(year) else 28
    if month in (4, 6, 9, 11):
        return 30
    return 31


def _is_dcf_datetime_plausible(now: tuple) -> bool:
    """Prüft, ob eine DCF-Zeitangabe in plausiblen Grenzen liegt.

    Parameter
    ---------
    * now: DCF-Zeit als Tupel (Y, M, D, weekday, h, m, s)

    Returns
    -------
    * bool: True bei plausiblen Werten
    """
    year, month, day, dcf_weekday, hour, minute, second = now
    if not (DCF_MIN_YEAR <= year <= 2099):
        return False
    if not (1 <= month <= 12):
        return False
    if not (1 <= day <= _days_in_month(year, month)):
        return False
    if not (1 <= dcf_weekday <= 7):
        return False
    if not (0 <= hour <= 23 and 0 <= minute <= 59 and 0 <= second <= 59):
        return False
    return True


def _to_epoch_seconds(year: int, month: int, day: int, hour: int, minute: int, second: int) -> int:
    """Wandelt Datum/Zeit in Unix-Epoch-Sekunden um.

    Parameter
    ---------
    * year: Jahr
    * month: Monat
    * day: Tag
    * hour: Stunde
    * minute: Minute
    * second: Sekunde

    Returns
    -------
    * int: Epoch-Zeit in Sekunden
    """
    try:
        return time.mktime((year, month, day, hour, minute, second, 0, 0))
    except TypeError:
        return time.mktime((year, month, day, hour, minute, second, 0, 0, 0))


def _is_sync_jump_acceptable(dcf_now: tuple, rtc_now: "tuple | None") -> bool:
    """Prüft, ob der DCF-Zeitsprung gegenüber RTC akzeptabel ist.

    Parameter
    ---------
    * dcf_now: Kandidat aus DCF als Tupel
    * rtc_now: Aktuelle RTC-Zeit als Tupel oder None

    Returns
    -------
    * bool: True, wenn Sprung innerhalb des Limits liegt
    """
    if rtc_now is None:
        return True

    rtc_year = rtc_now[0]
    if rtc_year < DCF_MIN_YEAR:
        ## RTC ist noch uninitialisiert oder hat Default-Zeit.
        return True

    try:
        dcf_epoch = _to_epoch_seconds(dcf_now[0], dcf_now[1], dcf_now[2], dcf_now[4], dcf_now[5], dcf_now[6])
        rtc_epoch = _to_epoch_seconds(rtc_now[0], rtc_now[1], rtc_now[2], rtc_now[4], rtc_now[5], rtc_now[6])
    except Exception:
        return False

    delta = abs(dcf_epoch - rtc_epoch)
    return delta <= MAX_SYNC_JUMP_SECONDS


def _is_dcf_progress_consistent(prev_dcf: tuple, prev_ticks, curr_dcf: tuple, curr_ticks) -> bool:
    """Prüft, ob DCF-Zeitfortschritt zur real verstrichenen Zeit passt.

    Parameter
    ---------
    * prev_dcf: Vorherige DCF-Zeit
    * prev_ticks: Tick-Zeitstempel der vorherigen DCF-Zeit
    * curr_dcf: Aktuelle DCF-Zeit
    * curr_ticks: Tick-Zeitstempel der aktuellen DCF-Zeit

    Returns
    -------
    * bool: True bei konsistentem Fortschritt
    """
    try:
        prev_epoch = _to_epoch_seconds(prev_dcf[0], prev_dcf[1], prev_dcf[2], prev_dcf[4], prev_dcf[5], prev_dcf[6])
        curr_epoch = _to_epoch_seconds(curr_dcf[0], curr_dcf[1], curr_dcf[2], curr_dcf[4], curr_dcf[5], curr_dcf[6])
    except Exception:
        return False

    dcf_delta = curr_epoch - prev_epoch
    elapsed_seconds = time.ticks_diff(curr_ticks, prev_ticks) // 1000

    if dcf_delta <= 0:
        return False

    return abs(dcf_delta - elapsed_seconds) <= DCF_PROGRESS_TOLERANCE_SECONDS


def should_accept_dcf_sync(dcf_now: tuple, rtc_now: "tuple | None", recv_ticks) -> tuple:
    """Entscheidet, ob eine DCF-Zeit für Synchronisation akzeptiert wird.

    Parameter
    ---------
    * dcf_now: Kandidat aus DCF als Tupel
    * rtc_now: Aktuelle RTC-Zeit als Tupel oder None
    * recv_ticks: Tick-Zeitstempel beim Empfang

    Returns
    -------
    * tuple: (accepted, reason)
    """
    global _last_dcf_candidate, _last_dcf_candidate_ticks

    if not _is_dcf_datetime_plausible(dcf_now):
        return False, "DCF-Zeit außerhalb Plausibilitätsbereich"

    if not _is_sync_jump_acceptable(dcf_now, rtc_now):
        return False, "DCF-Sprung zur RTC zu groß"

    if _last_dcf_candidate is None or _last_dcf_candidate_ticks is None:
        _last_dcf_candidate = dcf_now
        _last_dcf_candidate_ticks = recv_ticks
        return False, "warte auf zeitkonsistente Folge"

    if not _is_dcf_progress_consistent(_last_dcf_candidate, _last_dcf_candidate_ticks, dcf_now, recv_ticks):
        _last_dcf_candidate = dcf_now
        _last_dcf_candidate_ticks = recv_ticks
        return False, "DCF-Folge zeitlich inkonsistent"

    _last_dcf_candidate = dcf_now
    _last_dcf_candidate_ticks = recv_ticks
    return True, "ok"

## --- Async-Tasks -------------------------------------------------------------

async def update_display():
    """Aktualisiert die Anzeige im Sekundentakt.

    Returns
    -------
    * None
    """
    while True:
        global _latest_temp, _latest_hum

        ## Wir lesen hier die INTERNE ESP-RTC (sehr schnell)
        now = rtc_internal.datetime()  # Format: (year, month, day, weekday, hours, minutes, seconds)
        print(f"[DISPLAY] {now[0]}-{now[1]:02d}-{now[2]:02d} | {now[4]:02d}:{now[5]:02d}:{now[6]:02d}")

        ## Display löschen
        display.clear()
        ## 1a) Anzeige der Uhrzeit im Format "HH:MM:SS"
        # time_str = f"{now[4]:02d}:{now[5]:02d}:{now[6]:02d}"
        ## 1b) Anzeige der Uhrzeit im Format "H:MM" mit blinkendem Doppelpunkt
        if now[6] % 2 == 0:
            time_str = f"{now[4]:d}:{now[5]:02d}"
        else:
            time_str = f"{now[4]:d} {now[5]:02d}"
        display.write_text_centered(time_str, 1, max7219wrapper.FONT_5X7, row=0)
        ## 2) Sensorwerte auf der zweiten Zeile anzeigen (z.B. Temperatur und Luftfeuchtigkeit)
        if _latest_temp is None or _latest_hum is None:
            display.write_text_centered("----", 1, max7219wrapper.FONT_5X7, row=1)
        else:
            if now[6] % 10 < 5:
                display.write_text_centered(f"{_latest_temp:.1f} °C", 1, max7219wrapper.FONT_5X7, row=1)
            else:
                display.write_text_centered(f"{_latest_hum:.1f} %", 1, max7219wrapper.FONT_5X7, row=1)
        ## Neue Anzeige schalten
        display.show()

        # await asyncio.sleep(1)
        ## DRIFT-KOMPENSATION
        ## Wir berechnen, wie viele Millisekunden bis zur nächsten vollen Sekunde fehlen.
        ## Das verhindert, dass die Anzeige langsam "wandert".
        ms_to_next_second = 1000 - (time.ticks_ms() % 1000)  # type: ignore[operator]  # ty: ignore[unsupported-operator]
        await asyncio.sleep_ms(ms_to_next_second)


async def read_sensors():
    """Liest periodisch Sensorwerte und schreibt sie ins Log.

    Returns
    -------
    * None
    """
    global _latest_temp, _latest_hum, _latest_lux_perc

    while True:
        temp, hum = temphum_sensor.get_measurement()
        _, lux_perc = light_sensor.get_measurement()

        _latest_temp = temp
        _latest_hum = hum
        _latest_lux_perc = lux_perc

        print(f"[SENSORS] {temp:.2f} °C | {hum:.2f} %rF | {lux_perc:.1f} %ADC")

        ## Anpassung der Display-Helligkeit
        if lux_perc is not None and display is not None:
            ## Wir skalieren die Helligkeit von 0-40% auf 0-15 (MAX7219-Helligkeitsstufen)
            brightness = int((lux_perc / 40) * 15)
            brightness = max(0, min(15, brightness))  # Begrenzung auf gültigen Bereich
            print(f"[SENSORS] Setze Display-Helligkeit auf {brightness} (für {lux_perc:.1f}% Licht)")
            display.brightness(brightness)

        await asyncio.sleep(5)


async def sync_time():
    """Synchronisiert Zeit von DCF77 zur externen und internen RTC.

    Returns
    -------
    * None
    """
    while True:
        ## Zeit des DCF-Moduls auslesen und RTCs synchronisieren
        if dcf.sync_ready:
            dcf.sync_ready = False  # Flag zurücksetzen
            dcf_now = dcf.current_time  # DCF: (year, month, day, weekday(1..7), hours, minutes, seconds)
            if dcf_now is None:
                print("[SYNC] DCF-Signal meldete sync_ready ohne Zeitwert")
                await asyncio.sleep(1)
                continue

            print(f"[SYNC] Neue DCF-Zeit empfangen: {dcf_now}")
            rtc_now = rtc_external.get_rtc_time()
            recv_ticks = time.ticks_ms()

            accepted, reason = should_accept_dcf_sync(dcf_now, rtc_now, recv_ticks)
            if accepted:
                ## Externe RTC synchronisieren: DCF-Zeit -> Externe RTC
                year, month, day, dcf_weekday, hour, minute, second = dcf_now
                machine_weekday = rv8263.RV8263.dcf_weekday_to_machine(dcf_weekday)
                rtc_external.set_rtc_time(year, month, day, machine_weekday, hour, minute, second)
                print("[SYNC] DCF-Zeit auf RTC übernommen")
            else:
                print(f"[SYNC] DCF-Zeit verworfen ({reason}): {dcf_now}")

            ## Interne RTC synchronisieren: Externe RTC -> Interne RTC
            # now = rtc_external.get_rtc_time()  # Format: (year, month, day, weekday, hours, minutes, seconds)
            now = rtc_external.get_rtc_time_machine()  # Format: (year, month, day, weekday, hours, minutes, seconds, subseconds)
            if now is not None:
                rtc_internal.datetime(now)
                print("[SYNC] Interne RTC mit externer RTC synchronisiert")

        await asyncio.sleep(1)


##******************************************************************************
##******************************************************************************

async def main() -> None:
    """Startet alle asynchronen Tasks.

    Returns
    -------
    * None
    """
    print("Starte Event-Loop...")
    ## Wir nutzen gather, um alle Funktionen gleichzeitig "anzuwerfen"
    await asyncio.gather(
        dcf.run(),         # DCF-Background-Task
        read_sensors(),    # Sensoren (SHT31/Licht)
        sync_time(),       # Zeit-Synchronisation DCF77 > externe RTC > interne RTC
        update_display(),  # Display-Aktualisierung
    )

try:
    ## RTC-Sync Externe RTC -> Interne RTC zu Beginn, damit die Uhrzeit direkt korrekt ist
    rtc_now = rtc_external.get_rtc_time_machine()
    if rtc_now is not None:
        rtc_internal.datetime(rtc_now)
        print("[BOOT] Interne RTC mit externer RTC synchronisiert")
    asyncio.run(main())
except KeyboardInterrupt:
    ## Uhr gestoppt
    pass

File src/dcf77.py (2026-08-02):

import asyncio
import time

import machine


##==============================================================================
class DCF77:
    ##--------------------------------------------------------------------------
    def __init__(
        self,
        dcf_pin: machine.Pin,
        led_pin: machine.Pin | None = None,
        debounce_ms: int = 30,
        on_sync = None,
        verbose: bool = False,
    ) -> None:
        """Initialisiert den DCF77-Empfänger.

        Parameter
        ---------
        * pin_no: GPIO des DCF77-Datenpins
        * led_pin: GPIO der Status-LED
        * debounce_ms: Entprellzeit für Flanken in Millisekunden
        * on_sync: Optionaler Callback bei erfolgreicher Synchronisation
        * verbose: Aktiviert Debug-Ausgaben

        Returns
        -------
        * None
        """
        ## DCF77-Pin
        self.dcf_pin = dcf_pin
        ## Optionale Status-LED (z.B. interne LED, boardconfig.get_status_led_pin())
        if led_pin is None:
            self.led = None
        else:
            self.led = led_pin

        ## Debounce-Zeit in ms (typisch 20-50ms)
        self.debounce_ms = debounce_ms

        ## Variablen für die DCF-Logik
        self.bits = []
        self.last_change_time = time.ticks_ms()
        self.last_stable_state = self.dcf_pin.value()
        self.pulse_start_time = 0
        self.last_pulse_end = time.ticks_ms()
        self.sync_ready = False
        self.current_time = None  # (Jahr, Monat, Tag, Wochentag, Std, Min)
        self._line_open = False
        self.on_sync = on_sync
        self.verbose = verbose

    ##--------------------------------------------------------------------------
    def flush_output_line(self) -> None:
        """Sorgt für einen sauberen Zeilenumbruch bei Inline-Ausgaben.

        Returns
        -------
        * None
        """
        if self._line_open:
            self.printv()
            self._line_open = False

    ##--------------------------------------------------------------------------
    def _bcd_to_int(self, bit_list: list) -> int:
        """Konvertiert eine Liste von DCF-Bits in eine Ganzzahl.

        Parameter
        ---------
        * bit_list: Bitfolge im LSB-first-Format

        Returns
        -------
        * int: Dekodierter Zahlenwert
        """
        weights = [1, 2, 4, 8, 10, 20, 40, 80]
        val = 0
        for i, bit in enumerate(bit_list):
            # if i < len(weights) and bit:
            if bit:
                val += weights[i]
        return val

    ##--------------------------------------------------------------------------
    def _even_parity_ok(self, bits: list, parity_bit: int) -> bool:
        """Prüft DCF77-Parität (gerade Parität).

        Parameter
        ---------
        * bits: Nutzdatenbits
        * parity_bit: Zugehöriges Paritätsbit

        Returns
        -------
        * bool: True, wenn die Parität korrekt ist
        """
        return (sum(bits) + parity_bit) % 2 == 0

    ##--------------------------------------------------------------------------
    def _is_leap_year(self, year: int) -> bool:
        """Prüft, ob ein Jahr ein Schaltjahr ist.

        Parameter
        ---------
        * year: Kalenderjahr

        Returns
        -------
        * bool: True bei Schaltjahr
        """
        return (year % 4 == 0 and year % 100 != 0) or (year % 400 == 0)

    ##--------------------------------------------------------------------------
    def _days_in_month(self, year: int, month: int) -> int:
        """Gibt die Anzahl Tage eines Monats zurück.

        Parameter
        ---------
        * year: Kalenderjahr
        * month: Monat 1..12

        Returns
        -------
        * int: Anzahl Tage im Monat
        """
        if month == 2:
            return 29 if self._is_leap_year(year) else 28
        if month in (4, 6, 9, 11):
            return 30
        return 31

    ##--------------------------------------------------------------------------
    def _weekday_dcf_from_date(self, year: int, month: int, day: int) -> int:
        """Berechnet den DCF-Wochentag aus einem Datum.

        Parameter
        ---------
        * year: Kalenderjahr
        * month: Monat 1..12
        * day: Tag 1..31

        Returns
        -------
        * int: Wochentag im DCF-Format (1=Mo..7=So)
        """
        # Sakamoto-Algorithmus: 0=So..6=Sa
        month_table = [0, 3, 2, 5, 0, 3, 5, 1, 4, 6, 2, 4]
        y = year
        if month < 3:
            y -= 1
        weekday_sun0 = (y + y // 4 - y // 100 + y // 400 + month_table[month - 1] + day) % 7
        if weekday_sun0 == 0:
            return 7
        return weekday_sun0

    ##--------------------------------------------------------------------------
    def _select_telegram_bits(self) -> "list | None":
        """Wählt ein Telegrammfenster aus dem Bitpuffer.

        Returns
        -------
        * list: Letzte 59 bzw. 58 Bits oder None
        """
        if len(self.bits) >= 59:
            return self.bits[-59:]
        if len(self.bits) >= 58:
            return self.bits[-58:]
        return None

    ##--------------------------------------------------------------------------
    def printv(self, *args: object, end: str = "\n") -> None:
        """Gibt Debug-Text nur im Verbose-Modus aus.

        Parameter
        ---------
        * args: Beliebige Druckargumente
        * end: Zeilenende

        Returns
        -------
        * None
        """
        if self.verbose:
            print(*args, end=end)

    ##--------------------------------------------------------------------------
    def _decode_telegram(self, frame_bits: "list | None") -> "tuple | None":  # noqa: C901
        """Dekodiert ein DCF77-Frame in ein Datum/Zeit-Tupel.

        Parameter
        ---------
        * frame_bits: Telegramm-Bits (58 oder 59 Bits)

        Returns
        -------
        * tuple: (year, month, day, weekday, hour, minute, second) oder None
        """
        try:
            if frame_bits is None or len(frame_bits) < 58:
                return None

            ## Startbit (Sekunde 20) sollte 1 sein.
            if frame_bits[20] != 1:
                return None

            ## Paritätsprüfungen für Minute und Stunde.
            if not self._even_parity_ok(frame_bits[21:28], frame_bits[28]):
                return None
            if not self._even_parity_ok(frame_bits[29:35], frame_bits[35]):
                return None

            ## Datums-Parität nur prüfen, wenn das volle 59-Bit-Frame vorliegt.
            if len(frame_bits) >= 59:
                if not self._even_parity_ok(frame_bits[36:58], frame_bits[58]):
                    return None
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

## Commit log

2026-04-17 Docs, datasheets, wiring (wip)
2026-04-17 Update Wiring Diagram - NodeMCU ESP-32S (ESP-WROOM-32).svg
2026-04-20 Renamed modules (lower case); improved dcf77
2026-04-22 ESP-Pinout & Boardplan
2026-04-23 Added board layout
    [esp_power_switch_default_on.kicad_pcb, esp_power_switch_default_on.kicad_sch]
2026-04-27 Pinout adjusted for EasyEDA schematics
    [esp_power_switch_default_on.kicad_pcb, esp_power_switch_default_on.kicad_sch]
2026-05-03 Schematics & board layout draft
2026-05-05 Actual board devel
2026-05-07 Wiring updated to perfboard layout
2026-05-08 Consistent wiring diagrams, schematics and perfboard layout v1.0
2026-05-08 Fixed DCF77 plausibilty check
    [main.py]
2026-05-13 Added 2nd row (sensor values)
2026-05-14 Use only 5x7 font; higher SPI baudrate
2026-05-17 Added version vor ESP32-S3-WROOM-1
2026-07-28 Updated designator IDs and placement on schematic
2026-08-01 Updated for ESP32-S3-WROOM-1
2026-08-01 Updated for ESP32-S3-WROOM-1 (SVG)
2026-08-02 Updates pinout for both boards
2026-08-02 Pinouts as JSON per board variant with automatic detection
2026-08-02 Fixed code errors and type checking issues
    [basics.py, dcf77.py, dcf77_rawanalyzer1.py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]
